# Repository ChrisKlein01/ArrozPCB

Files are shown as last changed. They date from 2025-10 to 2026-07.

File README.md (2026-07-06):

# IoT System for Water Management in Rice Paddies

Embedded IoT system for LoRa + GPS telemetry, integrating custom hardware, embedded firmware, iterative PCB design, and a Node-RED backend.

## Final Prototype (V3)

The following images show selected views of the final hardware prototype (V3).

### Enclosure

<p align="center">
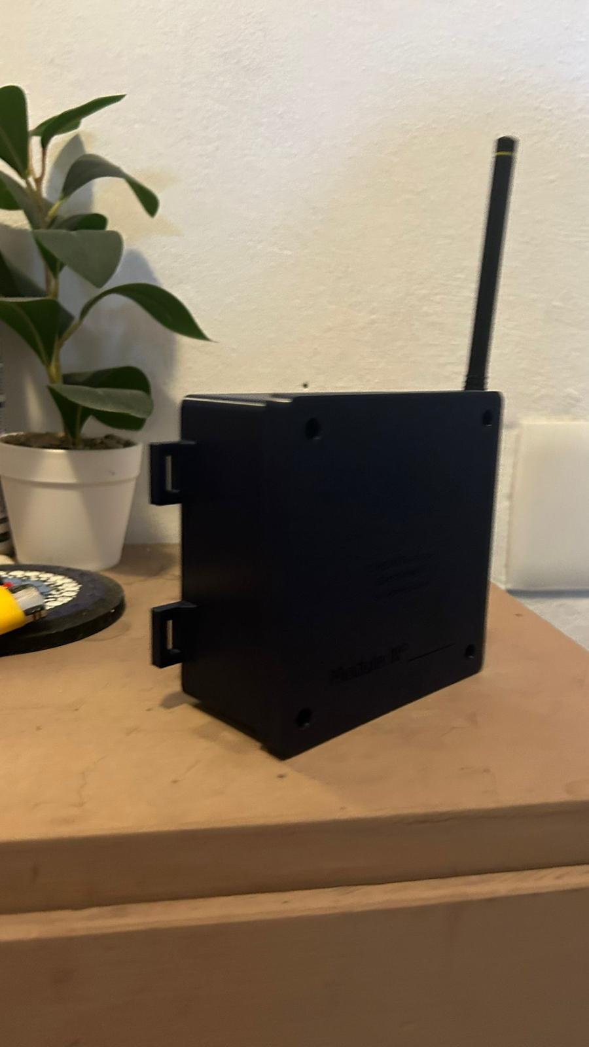
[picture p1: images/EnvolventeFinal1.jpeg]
  
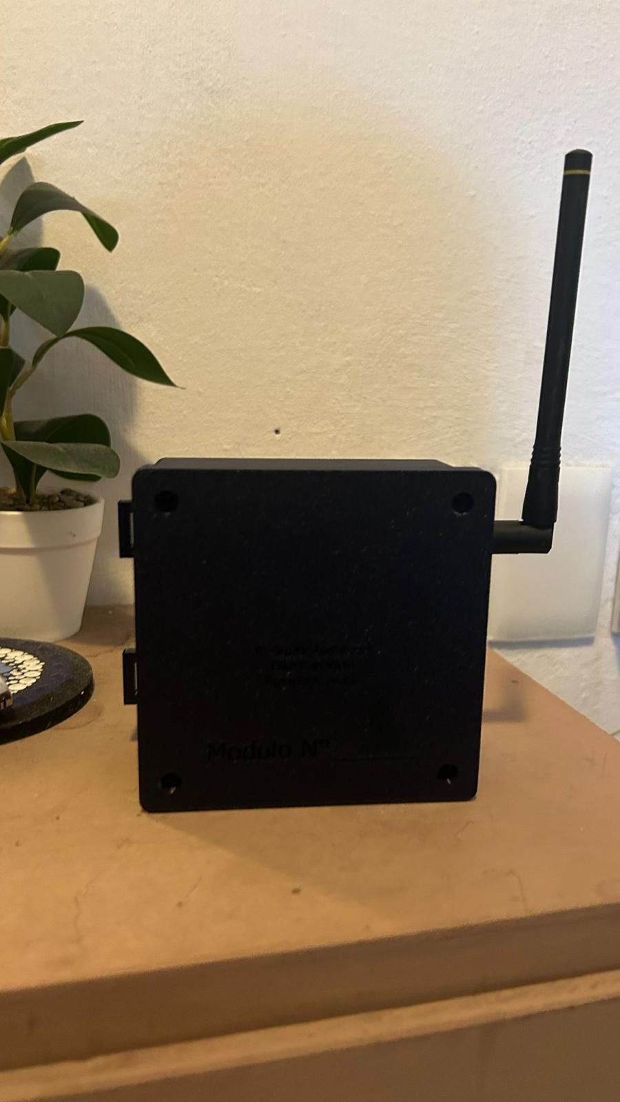
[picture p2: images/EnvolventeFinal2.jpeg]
  
</p>

### Custom PCB

<p align="center">
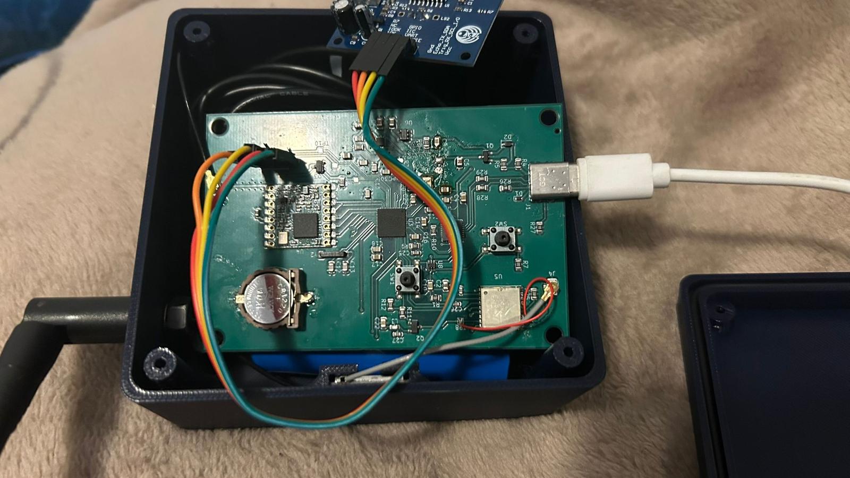
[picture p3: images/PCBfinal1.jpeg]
  
</p>

<p align="center">
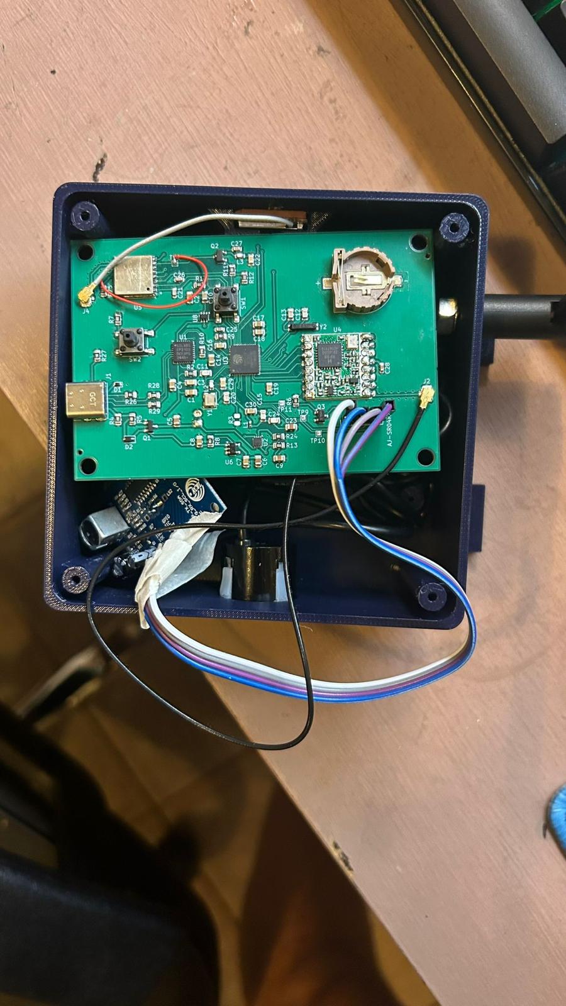
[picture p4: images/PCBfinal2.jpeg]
  
</p>

### Auxiliary Modules
For example, Power management and USB to UART modules.
<p align="center">
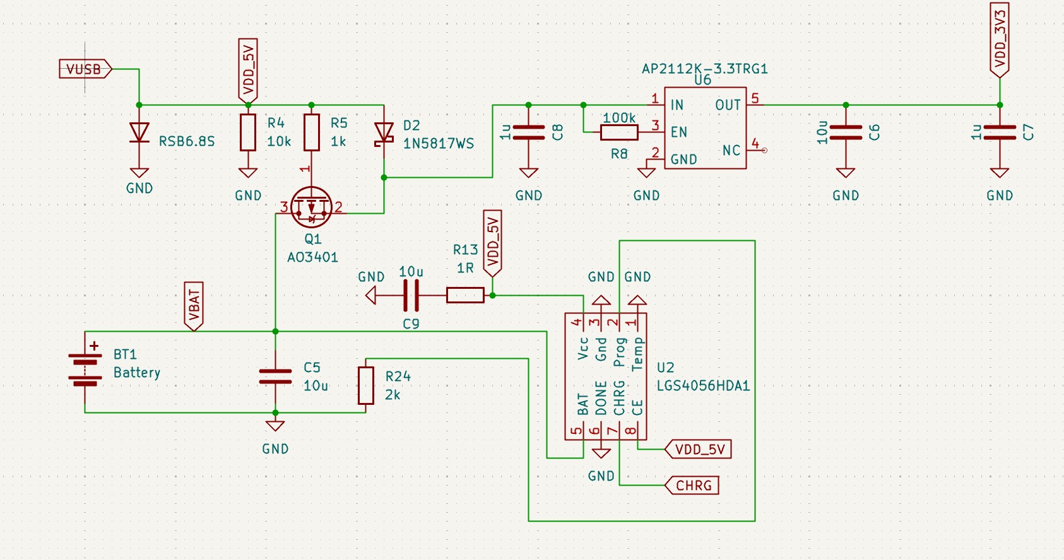
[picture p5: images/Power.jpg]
  
</p>

<p align="center">
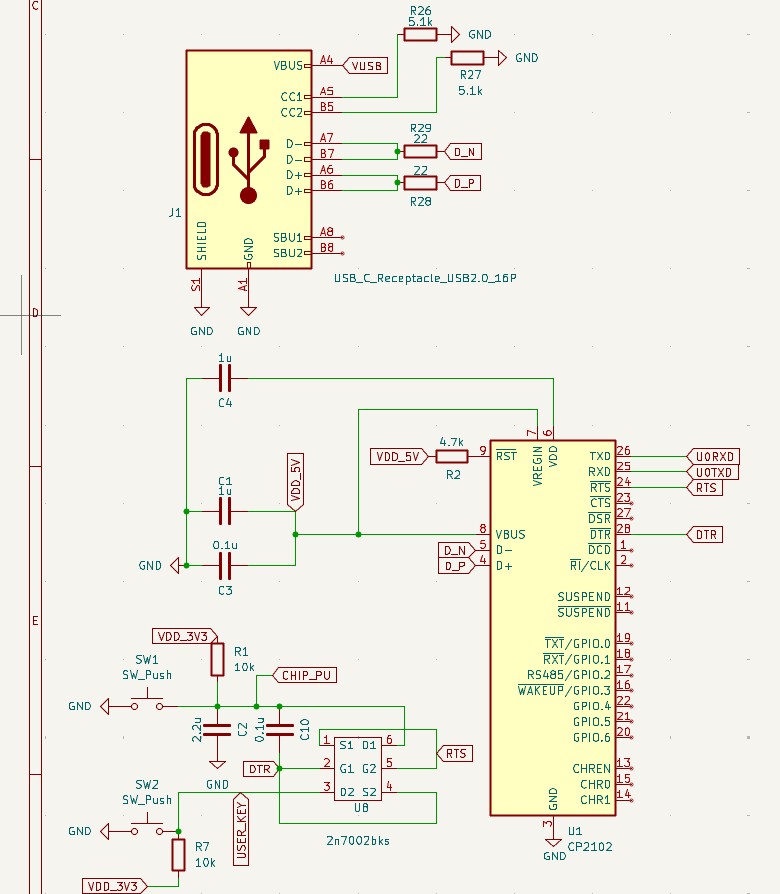
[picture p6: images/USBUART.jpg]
  
</p>

<h2>Firmware Flow Diagram</h2>

<p align="center">
  
</p>

## System Overview

End-to-end IoT prototype for wireless telemetry using LoRa communication and GPS data acquisition, covering proof-of-concept validation, custom hardware development, embedded firmware, iterative PCB design, and a complete Node-RED data processing pipeline.

---

## Repository Structure

- `Codigo_lilygo/`  
  Proof-of-concept implementation using a LilyGO T3 v1.6.1 development board. Used for early validation of LoRa communication and end-to-end data flow through an initial Node-RED pipeline before custom PCB and GPS integration.

- `Firmware/`  
  Main embedded firmware for the custom PCB. Handles GPS acquisition, LoRa communication, and system logic.

- `Node Red/`  
  Node-RED flows for telemetry ingestion, processing, and visualization.

- `Envolvente/`  
  Mechanical enclosure design for system housing and protection.

- `V1.0/`  
  First PCB iteration used to validate the custom LoRa hardware.

- `V2.0/`  
  PCB redesign incorporating GPS integration and correcting initial hardware issues.

- `V3.0/`  
  Final PCB revision with optimized layout and complete system integration.

- `.gitignore`  
  Git ignore rules for build artifacts and temporary files.

- `README.md`  
  Project documentation.

---

## Development Flow

1. Proof-of-concept on a LilyGO T3 development board.
2. Validation of LoRa communication and the initial telemetry pipeline using Node-RED.
3. Design and validation of the first custom PCB (V1.0).
4. PCB redesign with GPS integration and hardware improvements (V2.0).
5. Final optimized hardware revision with complete system integration (V3.0).
6. Integration with the Node-RED backend and end-to-end system validation.

---

## Project Scope

The project covers the complete development cycle of an embedded IoT system, including:

- Embedded firmware development (C/C++)
- Custom electronic circuit design
- Schematic capture and PCB design (KiCad)
- PCB assembly and soldering
- LoRa wireless communication
- GPS integration
- MQTT-based telemetry
- Node-RED backend development
- Mechanical enclosure design

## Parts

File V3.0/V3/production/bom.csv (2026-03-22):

Designator | Footprint | Quantity | Value | LCSC Part #
AJ-SR04M1 | PinHeader_1x04_P2.54mm_Vertical | 1 | U3 | C7243
BT1 | JST_EH_S2B-EH_1x02_P2.50mm_Horizontal | 1 | Battery
BT2 | pila | 1 | 1056TR | C238068
C1, C14, C17, C4, C7, C8 | 0805 | 6 | 1u
C10, C16, C18, C19, C3, C30 | 0805 | 6 | 0.1u
C11 | 0805 | 1 | 15p
C12, C13 | 0805 | 2 | 4.7p
C15 | 0805 | 1 | 2.2p
C2 | 0805 | 1 | 2.2u
C20 | 0805 | 1 | 18p
C21, C25, C26, C27 | 0603 | 4 | 56pF
C22 | 0805 | 1 | 10nF
C23, C5, C6, C9 | 0805 | 4 | 10u
C24 | 0805 | 1 | 1.8p
C28 | 0603 | 1 | 10u
C29 | 0805 | 1 | 10n
D1 | D_SOD-523 | 1 | RSB6.8S | C28646388
D2 | D_SOD-323 | 1 | 1N5817WS | C727114
J1 | USB_C_Receptacle_GCT_USB4085 | 1 | USB_C_Receptacle_USB2.0_16P | C7095263
J2, J4 | U.FL_Hirose_U.FL-R-SMT-1_Vertical | 2 | Conn_Coaxial_Small | C88373
L1 | 0402 | 1 | 2.0n | C18216
L2 | 0603 | 1 | 22n | C12099
L3 | 0603 | 1 | 27nH | C12100
Q1 | SOT-23 | 1 | AO3401 | C181091
Q2 | SOT-23 | 1 | AO3401A | C15127
Q3 | SOT-23 | 1 | AO3400A | C20917
R1, R12, R25, R4, R7 | 0805 | 5 | 10k
R10 | 0805 | 1 | 499
R11, R5 | 0805 | 2 | 1k
R13 | 0805 | 1 | 1R
R2 | 0805 | 1 | 4.7k
R24 | 0805 | 1 | 2k
R26, R27 | 0805 | 2 | 5.1k
R28, R29 | 0805 | 2 | 22
R3 | 0805 | 1 | 50 NC
R6, R8, R9 | 0805 | 3 | 100k
SW1, SW2 | SW_SPST_PTS645Sx43SMTR92 | 2 | SW_Push | C49234152
TP10, TP11, TP8, TP9 | TestPoint_Pad_1.0x1.0mm | 4 | TestPoint
U1 | QFN-28-1EP_5x5mm_P0.5mm_EP3.35x3.35mm | 1 | CP2102 | C6568
U2 | DFN-8-1EP_2x2mm_P0.5mm_EP0.6x1.2mm | 1 | LGS4056HDA1 | C5124109
U3 | QFN-56-1EP_7x7mm_P0.4mm_EP4x4mm | 1 | ESP32-S3FN8 | C2913196
U4 | HOPERF_RFM9XW_SMD | 1 | RFM95W-915S2
U5 | Teseo | 1 | TESEO-LIV3R
U6 | SOT-23-5 | 1 | AP2112K-3.3TRG1 | C23380830
U8 | SOT-363_SC-70-6 | 1 | 2n7002bks | C68181
Y1 | Crystal_SMD_3225-4Pin_3.2x2.5mm | 1 | Crystal 40MHz/10ppm | C5380316
Y2 | Crystal_SMD_SeikoEpson_MC146-4Pin_6.7x1.5mm | 1 | 32.768KHz/ESR≤70KΩ | C15482

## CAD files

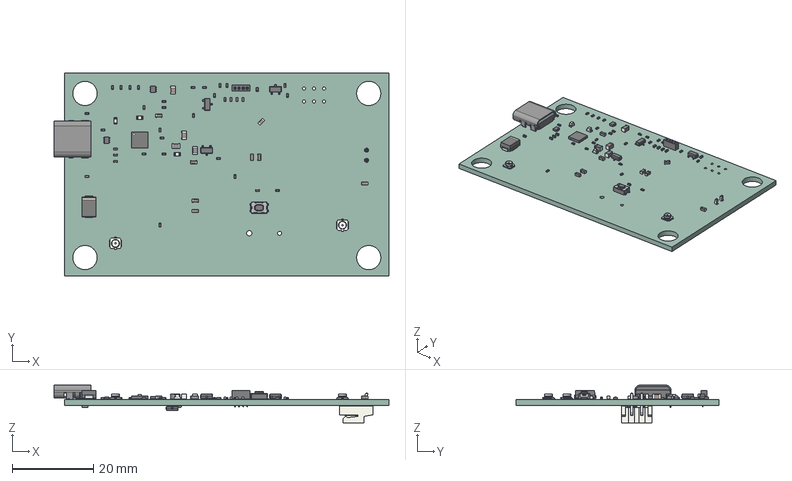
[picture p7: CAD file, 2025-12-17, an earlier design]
v2.0/PCB_LoRa+GPS.step
82.6 x 50.0 x 9.33 mm
C_0402_1005Metric x 10
C_0805_2012Metric x 2
R_0402_1005Metric x 27
LED_0603_1608Metric x 3
SOT-23 x 4
C_0603_1608Metric x 8
U.FL_Hirose_U.FL-R-SMT-1_Vertical x 2
SW_Push_1P1T_NO_CK_KMR2
D_SMB
QFN-24-1EP_4x4mm_P0.5mm_EP2.6x2.6mm
PinSocket_1x04_P1.00mm_Vertical
L_0805_2012Metric x 2
SOT-563
USB_C_Receptacle_GCT_USB4085
SOT-666
JST_EH_S2B-EH_1x02_P2.50mm_Horizontal
PCB_LoRa+GPS_PCB

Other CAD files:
Envolvente/CajaTesisV2.ipt

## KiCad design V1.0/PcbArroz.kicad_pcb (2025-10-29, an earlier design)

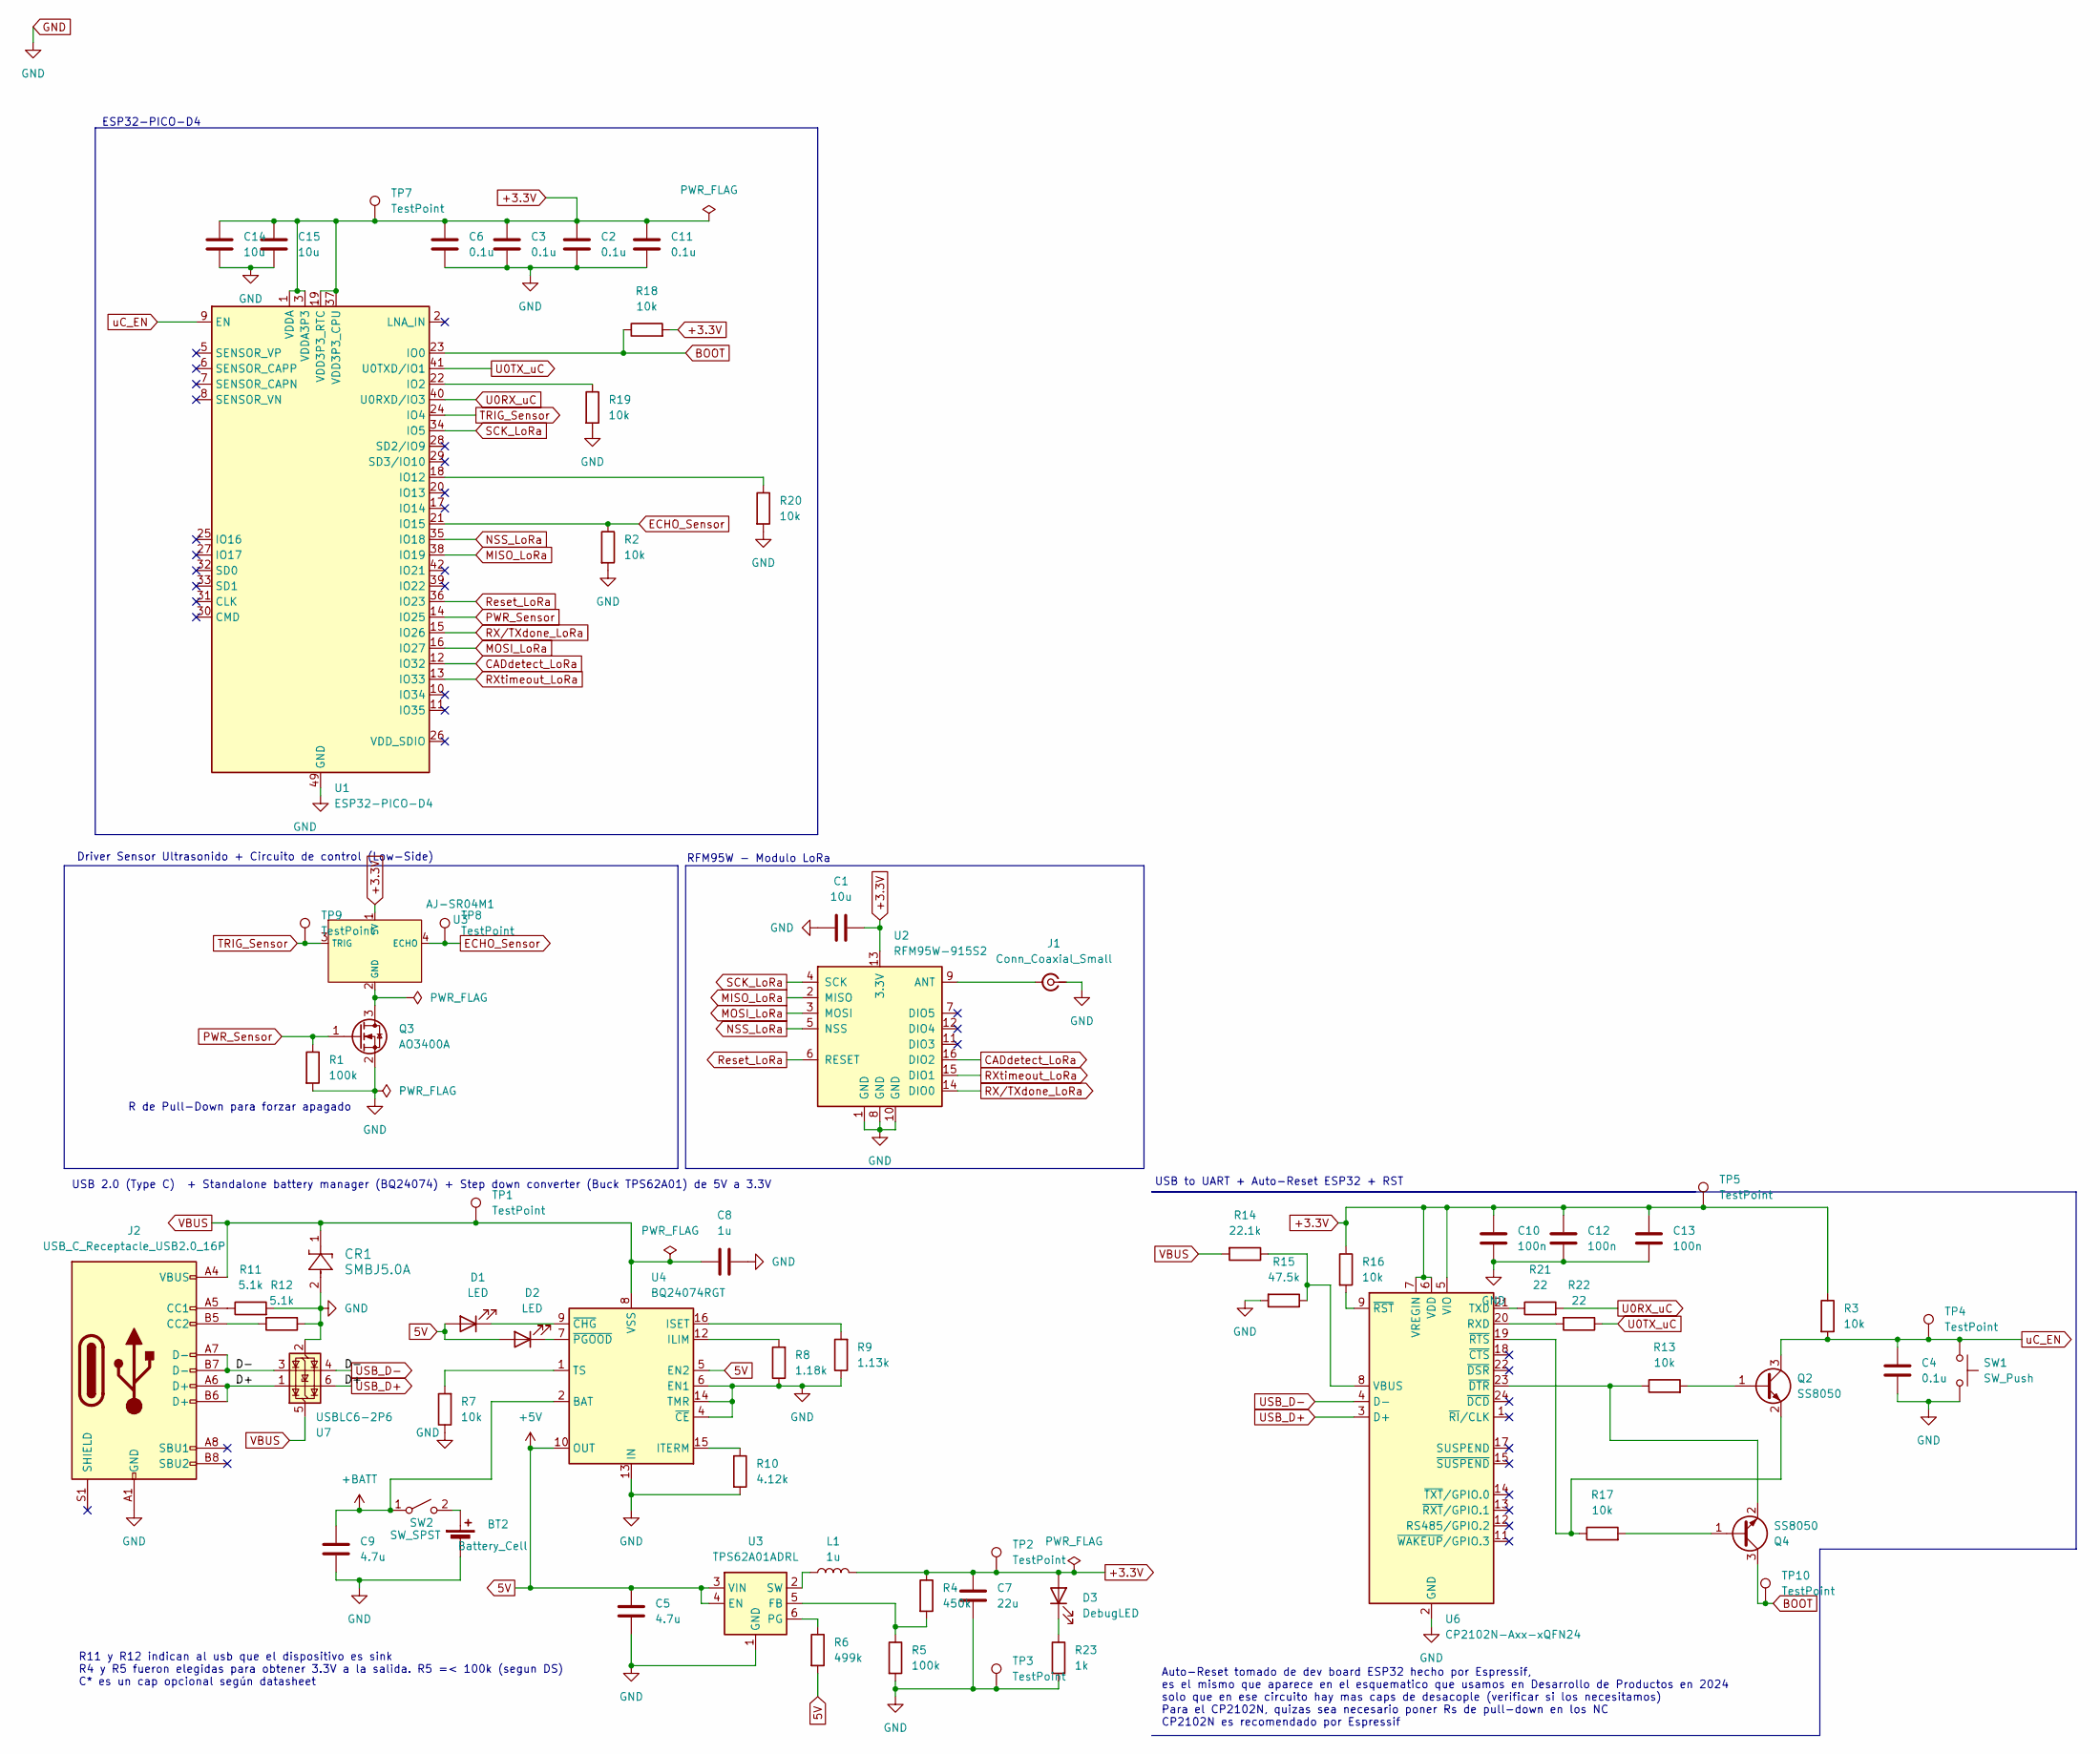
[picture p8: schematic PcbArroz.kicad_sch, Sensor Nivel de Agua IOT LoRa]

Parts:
AJ-SR04M1: U3; PinSocket_1x04_P2.54mm_Vertical
BT2: Battery_Cell; JST_EH_S2B-EH_1x02_P2.50mm_Horizontal
C1, C14, C15: 10u; C_0603_1608Metric
C2, C3, C4, C6, C11: 0.1u; C_0402_1005Metric
C5: 4.7u; C_0603_1608Metric
C7: 22u; C_0805_2012Metric
C8: 1u; C_0402_1005Metric
C9: 4.7u; C_0402_1005Metric
C10, C12, C13: 100n; C_0402_1005Metric
CR1: SMBJ5.0A; D_SMB
D1, D2: LED; LED_0603_1608Metric
D3: DebugLED; LED_0603_1608Metric
J1: Conn_Coaxial_Small; U.FL_Molex_MCRF_73412-0110_Vertical
J2: USB_C_Receptacle_USB2.0_16P; USB_C_Receptacle_GCT_USB4085
L1: 1u; C_0402_1005Metric
Q2, Q4: SS8050; SOT-23
Q3: AO3400A; SOT-23
R1, R5: 100k; R_0402_1005Metric
R2, R3, R7, R13, R16, R17, R18, R19, R20: 10k; R_0402_1005Metric
R4: 450k; R_0402_1005Metric
R6: 499k; R_0402_1005Metric
R8: 1.18k; R_0402_1005Metric
R9: 1.13k; R_0402_1005Metric
R10: 4.12k; R_0402_1005Metric
R11, R12: 5.1k; R_0402_1005Metric
R14: 22.1k; R_0402_1005Metric
R15: 47.5k; R_0402_1005Metric
R21, R22: 22; R_0402_1005Metric
R23: 1k; R_0402_1005Metric
SW1: SW_Push; SW_Push_1P1T_NO_Vertical_Wuerth_434133025816
SW2: SW_SPST; SW_DIP_SPSTx01_Slide_6.7x4.1mm_W7.62mm_P2.54mm_LowProfile
TP1, TP2, TP3, TP4, TP5, TP7, TP8, TP9, TP10: TestPoint; TestPoint_Pad_1.0x1.0mm
U1: ESP32-PICO-D4; QFN-48-1EP_7x7mm_P0.5mm_EP5.3x5.3mm
U2: RFM95W-915S2; HOPERF_RFM9XW_SMD
U3: TPS62A01ADRL; SOT-563
U4: BQ24074RGT; VQFN-16-1EP_3x3mm_P0.5mm_EP1.6x1.6mm
U6: CP2102N-Axx-xQFN24; QFN-24-1EP_4x4mm_P0.5mm_EP2.6x2.6mm
U7: USBLC6-2P6; SOT-666

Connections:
5V: C5.1, D1.2 (A), D2.2 (A), R6.2, U3.3 (VIN), U3.4 (EN), U4.5 (EN2), U4.10 (OUT), U4.11 (OUT)
+3.3V: AJ-SR04M1.1 (5V), C1.1, C2.1, C3.1, C6.1, C7.1, C10.1, C11.1, C12.1, C13.1, C14.1, C15.1, D3.2 (A), L1.2, R3.1, R4.1, R16.1, R18.2, TP2.1, TP5.1, TP7.1, U1.1 (VDDA), U1.3 (VDDA3P3), U1.4 (VDDA3P3), U1.19 (VDD3P3_RTC), U1.37 (VDD3P3_CPU), U1.43 (VDDA), U1.46 (VDDA), U2.13 (3.3V), U6.5 (VIO), U6.6 (VDD), U6.7 (VREGIN)
+BATT: C9.1, SW2.1 (A), U4.2 (BAT), U4.3 (BAT)
BOOT: Q4.3 (C), R18.1, TP10.1, U1.23 (IO0)
CADdetect_LoRa: U1.12 (IO32), U2.16 (DIO2)
ECHO_Sensor: AJ-SR04M1.4 (ECHO), R2.1, TP8.1, U1.21 (IO15)
GND: BT2.2 (-), C1.2, C2.2, C3.2, C4.2, C5.2, C6.2, C7.2, C8.1, C9.2, C10.2, C11.2, C12.2, C13.2, C14.2, C15.2, CR1.2, J1.1 (In), J2.A1 (GND), J2.A12 (GND), J2.B1 (GND), J2.B12 (GND), Q3.2 (S), R1.2, R2.2, R5.2, R7.1, R8.1, R9.1, R10.2, R11.2, R12.1, R15.2, R19.2, R20.2, R23.2, SW1.2, TP3.1, U1.49 (GND), U2.1 (GND), U2.8 (GND), U2.10 (GND), U3.1 (GND), U4.4 (~CE), U4.6 (EN1), U4.13 (IN), U4.14 (TMR), U6.2 (GND), U6.25 (GND), U7.2 (GND)
MISO_LoRa: U1.38 (IO19), U2.2 (MISO)
MOSI_LoRa: U1.16 (IO27), U2.3 (MOSI)
NSS_LoRa: U1.35 (IO18), U2.5 (NSS)
unnamed: AJ-SR04M1.2 (GND), Q3.3 (D)
unnamed: BT2.1 (+), SW2.2 (B)
unnamed: D1.1 (K), U4.9 (~CHG)
unnamed: D2.1 (K), U4.7 (~PGOOD)
unnamed: D3.1 (K), R23.1
unnamed: J1.2 (Ext), U2.9 (ANT)
unnamed: J2.A5 (CC1), R11.1
unnamed: J2.B5 (CC2), R12.2
unnamed: Q2.1 (B), R13.2
unnamed: Q2.2 (E), R17.1, U6.19 (~RTS)
unnamed: Q4.1 (B), R17.2
unnamed: Q4.2 (E), R13.1, U6.23 (~DTR)
unnamed: R19.1, U1.22 (IO2)
unnamed: R20.1, U1.18 (IO12)
unnamed: R4.2, R5.1, U3.5 (FB)
unnamed: R6.1, U3.6 (PG)
unnamed: L1.1, U3.2 (SW)
unnamed: R8.2, U4.12 (ILIM)
unnamed: R9.2, U4.16 (ISET)
unnamed: R10.1, U4.15 (ITERM)
unnamed: R7.2, U4.1 (TS)
unnamed: R22.2, U6.20 (RXD)
unnamed: R21.1, U6.21 (TXD)
unnamed: R14.1, R15.1, U6.8 (VBUS)
unnamed: R16.2, U6.9 (~RST)
PWR_Sensor: Q3.1 (G), R1.1, U1.14 (IO25)
RXtimeout_LoRa: U1.13 (IO33), U2.15 (DIO1)
RX/TXdone_LoRa: U1.15 (IO26), U2.14 (DIO0)
Reset_LoRa: U1.36 (IO23), U2.6 (RESET)
SCK_LoRa: U1.34 (IO5), U2.4 (SCK)
TRIG_Sensor: AJ-SR04M1.3 (TRIG), TP9.1, U1.24 (IO4)
U0RX_uC: R21.2, U1.40 (U0RXD/IO3)
U0TX_uC: R22.1, U1.41 (U0TXD/IO1)
USB_D+: J2.A6 (D+), J2.B6 (D+), U6.3 (D+), U7.1 (I/O1), U7.6 (I/O1)
USB_D-: J2.A7 (D-), J2.B7 (D-), U6.4 (D-), U7.3 (I/O2), U7.4 (I/O2)
VBUS: C8.2, CR1.1, J2.A4 (VBUS), J2.A9 (VBUS), J2.B4 (VBUS), J2.B9 (VBUS), R14.2, TP1.1, U4.8 (VSS), U4.17 (VSS), U7.5 (VBUS)
uC_EN: C4.1, Q2.3 (C), R3.2, SW1.1, TP4.1, U1.9 (EN)

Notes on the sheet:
Auto-Reset tomado de dev board ESP32 hecho por Espressif, es el mismo que aparece en el esquematico que usamos en Desarrollo de Productos en 2024 solo que en ese circuito hay mas caps de desacople (verificar si los necesitamos) Para el CP2102N, quizas sea necesario poner Rs de pull-down en los NC C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
USB to UART + Auto-Reset ESP32 + RST
Driver Sensor Ultrasonido + Circuito de control (Low-Side)
USB 2.0 (Type C) + Standalone battery manager (BQ24074) + Step down converter (Buck TPS62A01) de 5V a 3.3V
ESP32-PICO-D4
R de Pull-Down para forzar apagado
R11 y R12 indican al usb que el dispositivo es sink R4 y R5 fueron elegidas para obtener 3.3V a la salida. R5 =< 100k (segun DS) C* es un cap opcional según datasheet
RFM95W - Modulo LoRa

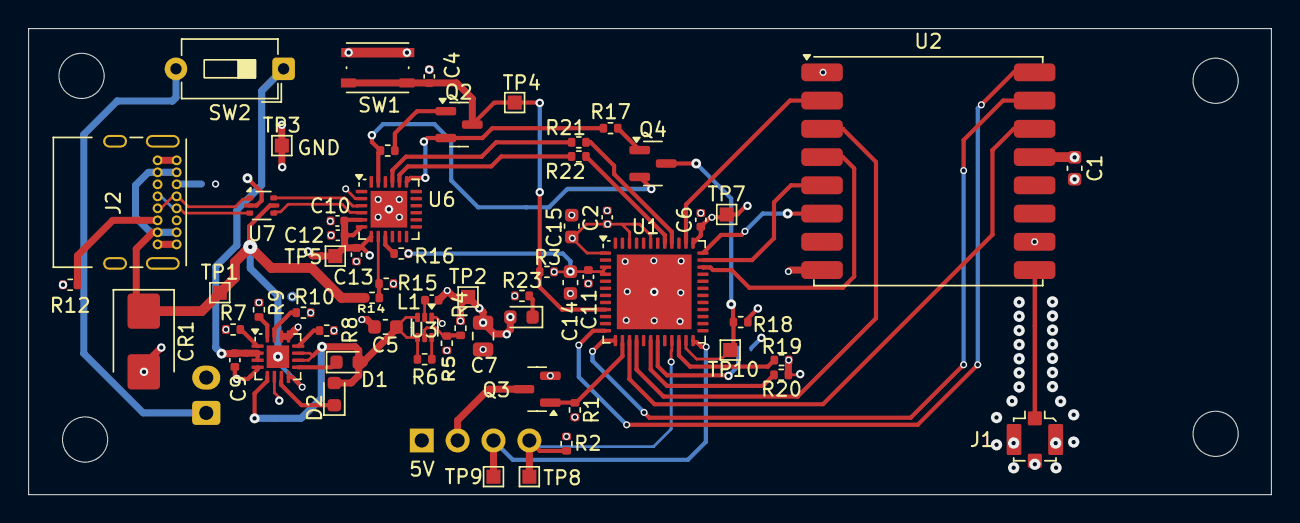
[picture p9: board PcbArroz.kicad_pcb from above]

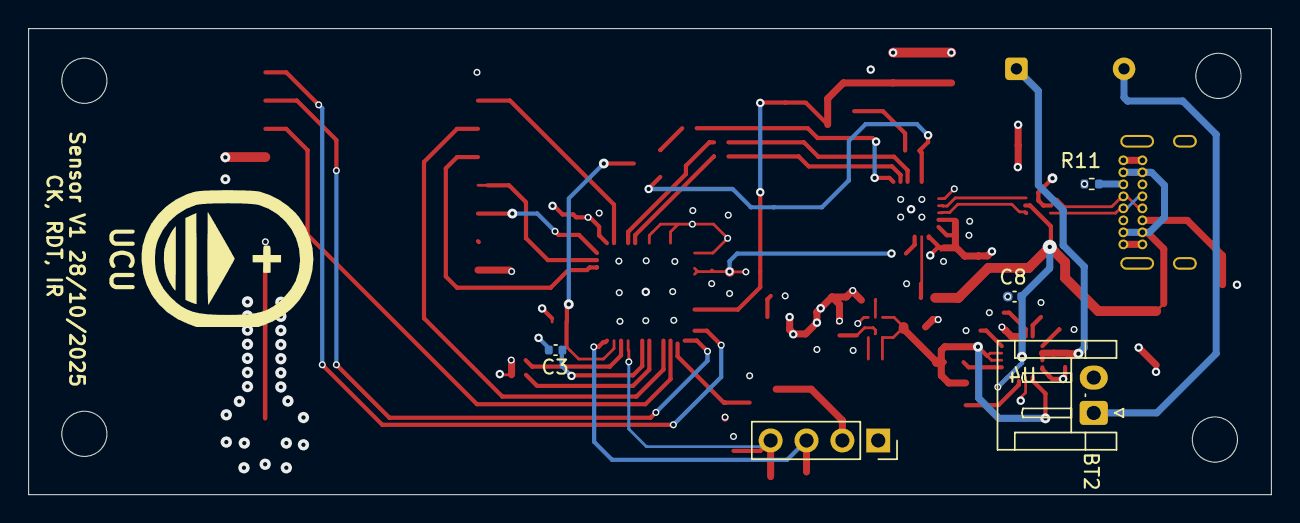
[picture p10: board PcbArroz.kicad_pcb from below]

Board: 4 copper layers, 88.0 x 33.0 mm, 68 parts (6 on the bottom side), 47 nets.

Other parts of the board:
UCU: LOGO; LogoUCU

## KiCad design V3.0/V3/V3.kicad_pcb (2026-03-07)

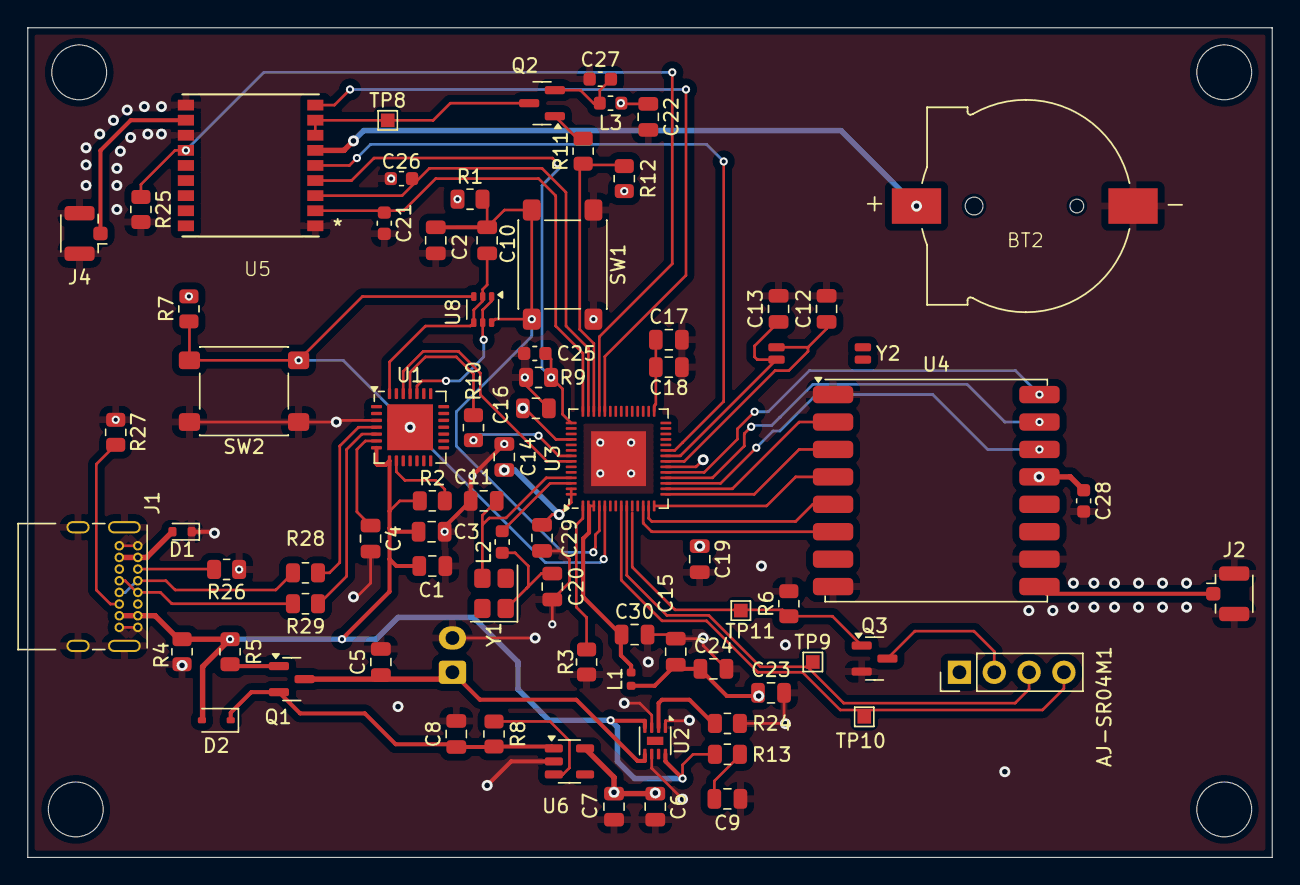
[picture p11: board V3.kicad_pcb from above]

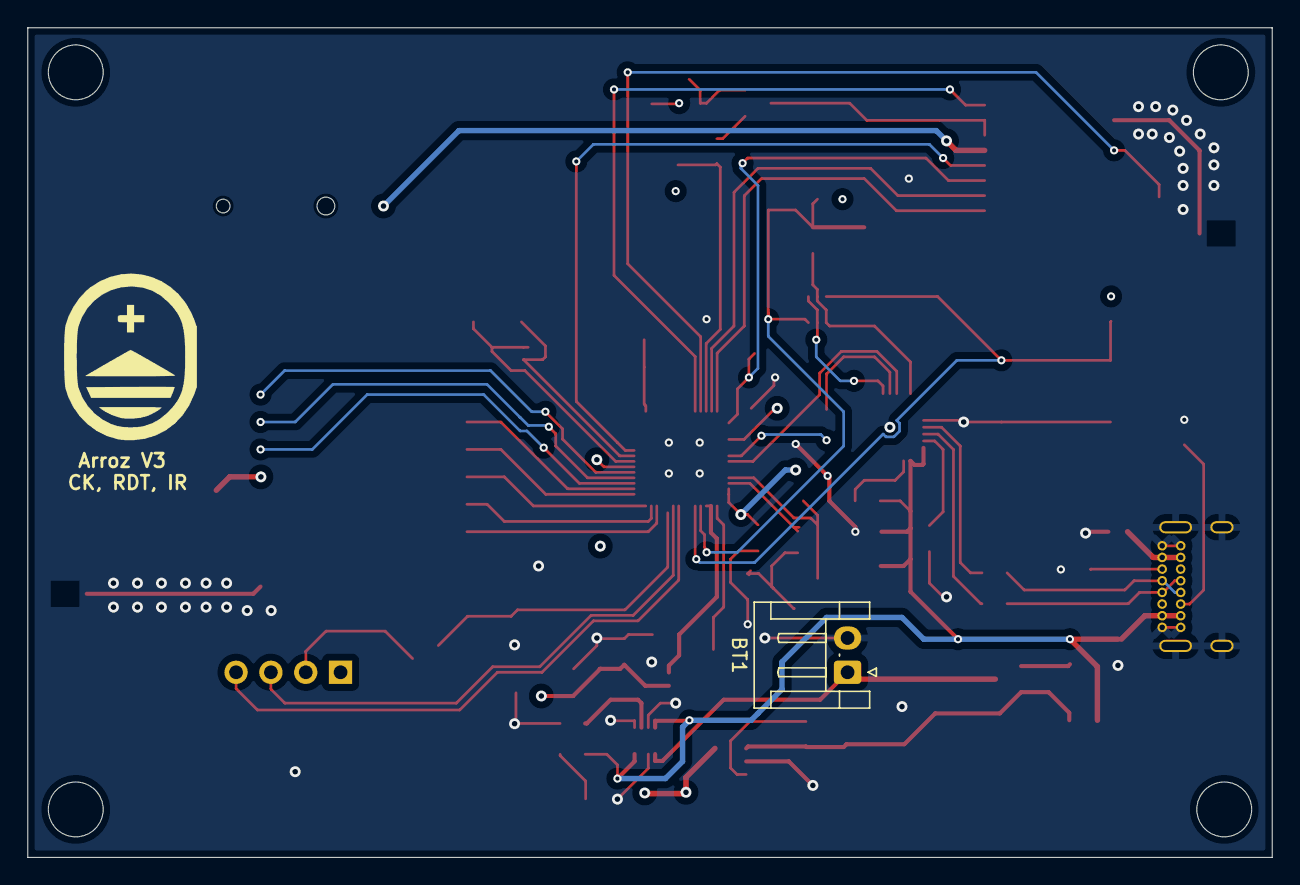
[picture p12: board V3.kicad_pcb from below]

Board: 4 copper layers, 90.8 x 60.5 mm, 79 parts (2 on the bottom side), 57 nets.

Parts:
AJ-SR04M1: U3; PinHeader_1x04_P2.54mm_Vertical
BT1: Battery; JST_EH_S2B-EH_1x02_P2.50mm_Horizontal
BT2: 1056TR; pila
C1, C4, C7, C8, C14, C17: 1u; C_0805_2012Metric
C2: 2.2u; C_0805_2012Metric
C3, C10, C16, C18, C19, C30: 0.1u; C_0805_2012Metric
C5, C6, C9, C23: 10u; C_0805_2012Metric
C11: 15p; C_0805_2012Metric
C12, C13: 4.7p; C_0805_2012Metric
C15: 2.2p; C_0805_2012Metric
C20: 18p; C_0805_2012Metric
C21, C25, C26, C27: 56pF; C_0603_1608Metric
C22: 10nF; C_0805_2012Metric
C24: 1.8p; C_0805_2012Metric
C28: 10u; C_0603_1608Metric
C29: 10n; C_0805_2012Metric
D1: RSB6.8S; D_SOD-523
D2: 1N5817WS; D_SOD-323
J1: USB_C_Receptacle_USB2.0_16P; USB_C_Receptacle_GCT_USB4085
J2, J4: Conn_Coaxial_Small; U.FL_Hirose_U.FL-R-SMT-1_Vertical
L1: 2.0n; L_0402_1005Metric
L2: 22n; L_0603_1608Metric
L3: 27nH; L_0603_1608Metric
Q1: AO3401; SOT-23
Q2: AO3401A; SOT-23
Q3: AO3400A; SOT-23
R1, R4, R7, R12, R25: 10k; R_0805_2012Metric
R2: 4.7k; R_0805_2012Metric
R3: 50 NC; R_0805_2012Metric
R5, R11: 1k; R_0805_2012Metric
R6, R8, R9: 100k; R_0805_2012Metric
R10: 499; R_0805_2012Metric
R13: 1R; R_0805_2012Metric
R24: 2k; R_0805_2012Metric
R26, R27: 5.1k; R_0805_2012Metric
R28, R29: 22; R_0805_2012Metric
SW1, SW2: SW_Push; SW_SPST_PTS645Sx43SMTR92
TP8, TP9, TP10, TP11: TestPoint; TestPoint_Pad_1.0x1.0mm
U1: CP2102; QFN-28-1EP_5x5mm_P0.5mm_EP3.35x3.35mm
U2: LGS4056HDA1; DFN-8-1EP_2x2mm_P0.5mm_EP0.6x1.2mm
U3: ESP32-S3FN8; QFN-56-1EP_7x7mm_P0.4mm_EP4x4mm
U4: RFM95W-915S2; HOPERF_RFM9XW_SMD
U5: TESEO-LIV3R; Teseo
U6: AP2112K-3.3TRG1; SOT-23-5
U8: 2n7002bks; SOT-363_SC-70-6
UCU: LOGO; LogoUCU
Y1: Crystal 40MHz/10ppm; Crystal_SMD_3225-4Pin_3.2x2.5mm
Y2: 32.768KHz/ESR≤70KΩ; Crystal_SMD_SeikoEpson_MC146-4Pin_6.7x1.5mm

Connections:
32K_XN: C13.1, U3.22 (XTAL_32K_N), Y2.1
32K_XP: C12.1, U3.21 (XTAL_32K_P), Y2.4
AntOff_GPS: R25.1, U3.39 (GPIO34), U5.13 (ANT_OFF)
CADdetect_LoRa: U3.19 (GPIO14), U4.16 (DIO2)
CHIP_PU: C2.1, C10.1, R1.2, SW1.2, U3.4 (CHIP_PU), U8.6 (D1)
DTR: C10.2, U1.28 (~DTR), U8.2 (G1), U8.4 (S2)
D_N: R29.1, U1.5 (D-)
D_P: R28.1, U1.4 (D+)
ECHO_Sensor: AJ-SR04M1.4 (ECHO), TP10.1, U3.8 (GPIO3)
GND: BT1.2 (-), BT2.N, C1.2, C2.2, C3.2, C4.2, C5.2, C6.2, C7.2, C8.2, C9.2, C11.2, C12.2, C13.2, C14.2, C15.2, C16.2, C17.2, C18.2, C19.2, C20.2, C21.2, C22.2, C23.2, C24.2, C25.2, C26.2, C27.1, C28.2, C29.2, C30.2, D1.1 (K), J1.A1 (GND), J1.A12 (GND), J1.B1 (GND), J1.B12 (GND), J1.S1 (SHIELD), J2.2 (Ext), J4.2 (Ext), Q3.2 (S), R3.2, R4.2, R6.2, R9.2, R24.1, R25.2, R26.1, R27.1, SW1.1, SW2.1, U1.3 (GND), U1.29 (GND), U2.1 (Temp), U2.3 (Gnd), U2.6 (DONE), U3.57 (GND), U4.1 (GND), U4.8 (GND), U4.10 (GND), U5.1 (GND), U5.10 (GND_RF), U5.12 (GND_RF), U6.2 (GND)
MISO_LoRa: U3.15 (GPIO10), U4.3 (MOSI)
MOSI_LoRa: U3.16 (GPIO11), U4.2 (MISO)
NSS_LoRa: U3.13 (GPIO8), U4.5 (NSS)
unnamed: AJ-SR04M1.2 (GND), Q3.3 (D)
unnamed: C9.1, R13.1
unnamed: C30.1, L1.2, U3.2 (VDD3P3), U3.3 (VDD3P3)
unnamed: C8.1, D2.1 (K), Q1.2 (S), R8.1, U6.1 (IN)
unnamed: J1.A5 (CC1), R26.2
unnamed: J1.B5 (CC2), R27.2
unnamed: J1.A6 (D+), J1.B6 (D+), R28.2
unnamed: J1.A7 (D-), J1.B7 (D-), R29.2
unnamed: J2.1 (In), U4.9 (ANT)
unnamed: J4.1 (In), U5.11 (RF_IN)
unnamed: Q1.1 (G), R5.2
unnamed: Q2.3 (D), TP8.1, U5.7 (VCC_IO), U5.8 (VCC)
unnamed: C27.2, L3.2, Q2.2 (S)
unnamed: C4.1, U1.6 (VDD)
unnamed: R2.2, U1.9 (~RST)
unnamed: R24.2, U2.2 (Prog)
unnamed: R11.1, R12.1, U3.40 (GPIO35)
unnamed: R3.1, U3.1 (LNA_IN)
unnamed: R10.2, U3.49 (U0TXD)
unnamed: C17.1, C18.1, U3.29 (VDD_SPI)
unnamed: L2.2, U3.54 (XTAL_P)
unnamed: R8.2, U6.3 (EN)
PPS_GPS: C25.1, R9.1, U3.43 (GPIO38), U5.4 (1PPS)
PWR_Sensor: Q3.1 (G), R6.1, TP11.1, U3.10 (GPIO5)
Pnp_Gps: Q2.1 (G), R11.2
RTS: U1.24 (~RTS), U8.1 (S1), U8.5 (G2)
RXtimeout_LoRa: U3.18 (GPIO13), U4.15 (DIO1)
RX/TXdone_LoRa: U3.17 (GPIO12), U4.14 (DIO0)
Reset_GPS: U3.38 (GPIO33), U5.9 (SYS_RSTn)
Reset_LoRa: U3.12 (GPIO7), U4.6 (RESET)
Rx_GPS: C26.1, U3.41 (GPIO36), U5.3 (RX)
SCK_LoRa: U3.14 (GPIO9), U4.4 (SCK)
TRIG_Sensor: AJ-SR04M1.3 (TRIG), TP9.1, U3.9 (GPIO4)
Tx_GPS: C21.1, U3.42 (GPIO37), U5.2 (TX)
U0RXD: U1.26 (TXD), U3.50 (U0RXD)
U0TXD: R10.1, U1.25 (RXD)
USER_KEY: R7.1, SW2.2, U3.5 (GPIO0), U8.3 (D2)
VBAT: BT1.1 (+), C5.1, Q1.3 (D), U2.5 (BAT)
VBatt: BT2.P, U5.6 (VBATT)
VDD_3V3: AJ-SR04M1.1 (5V), C6.1, C7.1, C14.1, C15.1, C16.1, C19.1, C22.1, C23.1, C24.1, C28.1, C29.1, L1.1, L3.1, R1.1, R7.2, R12.2, U3.20 (VDD3P3_RTC), U3.46 (VDD3P3_CPU), U3.55 (VDDA), U3.56 (VDDA), U4.13 (3.3V), U6.5 (OUT)
VDD_5V: C1.1, C3.1, D1.2 (A), D2.2 (A), J1.A4 (VBUS), J1.A9 (VBUS), J1.B4 (VBUS), J1.B9 (VBUS), R2.1, R4.1, R5.1, R13.2, U1.7 (VREGIN), U1.8 (VBUS), U2.4 (Vcc), U2.8 (CE)
Wake_GPS: U3.23 (GPIO17), U5.5 (Wake-Up)
XTAL_N: C11.1, U3.53 (XTAL_N), Y1.3
XTAL_P: C20.1, L2.1, Y1.1

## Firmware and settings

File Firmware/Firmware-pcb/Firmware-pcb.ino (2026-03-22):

/*
 * ============================================================================
 * MONITOREO NIVEL DE AGUA - ESP32-S3 + LoRaWAN + GPS
 * ============================================================================
 *
 * Hardware:
 *   - ESP32-S3
 *   - LoRa SX1276 / RFM95
 *   - Sensor ultrasónico RCWL-1655
 *   - GPS Teseo LIV3R
 *
 * Red: LoRaWAN OTAA via TTN / ChirpStack (US915)
 *
 * ----------------------------------------------------------------------------
 * FLUJOS DE EJECUCIÓN
 * ----------------------------------------------------------------------------
 *
 *   Primer boot:
 *     LoRa join → Medir → Enviar → GPS (90s) → Sleep
 *     (GPS queda en RTC para los ciclos siguientes)
 *
 *   Wake desde sleep (normal):
 *     Restaurar sesión → Medir → Enviar → Sleep
 *
 *   Wake desde sleep con downlink 0x03 pendiente:
 *     GPS (90s) → Restaurar sesión → Medir → Enviar → Sleep
 *     (coordenadas frescas en el payload de este ciclo)
 *
 * ----------------------------------------------------------------------------
 * PAYLOAD UPLINK (FPort 2) — 12 bytes
 * ----------------------------------------------------------------------------
 *   Byte  0     : flags de estado
 *                   bit 0 = GPS válido
 *                   bit 1 = medición de agua válida
 *                   bit 2 = GPS actualizado este ciclo
 *                   bit 3 = primer boot
 *   Byte  1-2   : nivel de agua en cm (uint16 big-endian, 0xFFFF = error)
 *   Byte  3-6   : latitud  × 10^6  (int32 big-endian)
 *   Byte  7-10  : longitud × 10^6  (int32 big-endian)
 *   Byte  11    : HDOP × 10 (uint8, 255 = inválido)
 *
 * ----------------------------------------------------------------------------
 * COMANDOS DOWNLINK (FPort 1)
 * ----------------------------------------------------------------------------
 *   0x01 [LSB] [MSB]  → cambiar intervalo en segundos (uint16 LE)
 *   0x02              → reiniciar placa
 *   0x03              → solicitar GPS en el próximo ciclo (timeout completo)
 *
 * ============================================================================
 */

#include <SPI.h>
#include <HardwareSerial.h>
#include <MicroNMEA.h>
#include <driver/rtc_io.h>
#include <esp_sleep.h>
#include <lmic.h>
#include <hal/hal.h>

// ============================================================================
// PINES
// ============================================================================

#define LORA_SCK      9
#define LORA_MISO    11
#define LORA_MOSI    10
#define LORA_NSS      8
#define LORA_RST      6
#define LORA_DIO0    12
#define LORA_DIO1    13
#define LORA_DIO2    14

#define TRIG_PIN         4
#define ECHO_PIN         3
#define SENSOR_PWR_PIN   5

#define GPS_RX      37
#define GPS_TX      36
#define PNP_GPS     35
#define RESET_GPS   33
#define PPS_PIN     38
#define ANT_OFF     34   // Output del Teseo — solo INPUT, no usar como salida
#define WAKE_GPS    17   // No utilizado

// ============================================================================
// CONFIGURACIÓN
// ============================================================================

#define ALTURA_SENSOR_CM   100
#define GPS_TIMEOUT_MS   450000
#define SENSOR_MUESTRAS       4
#define SENSOR_MIN_VALIDAS    2
#define DEFAULT_INTERVAL     2400

// ============================================================================
// CREDENCIALES OTAA
// ============================================================================

static const u1_t PROGMEM APPEUI[8] = {
    0x00, 0x00, 0x00, 0x00, 0x00, 0x00, 0x00, 0x00
};
static const u1_t PROGMEM DEVEUI[8] = {    //LSB
0xA1, 0x04, 0xCF, 0x4A, 0x79, 0x58, 0x29, 0x18
};
static const u1_t PROGMEM APPKEY[16] = {  //MSB
0xE2, 0x89, 0xD4, 0x61, 0xE7, 0xF2, 0x74, 0x56, 0xA4, 0x58, 0xE2, 0x98, 0x3B, 0x1D, 0xD7, 0x4C
};

void os_getArtEui(u1_t* buf) { memcpy_P(buf, APPEUI,  8); }
void os_getDevEui(u1_t* buf) { memcpy_P(buf, DEVEUI,  8); }
void os_getDevKey(u1_t* buf) { memcpy_P(buf, APPKEY, 16); }

const lmic_pinmap lmic_pins = {
    .nss            = LORA_NSS,
    .rxtx           = LMIC_UNUSED_PIN,
    .rst            = LORA_RST,
    .dio            = { LORA_DIO0, LORA_DIO1, LORA_DIO2 },
    .rxtx_rx_active = 0,
    .rssi_cal       = 10,
    .spi_freq       = 8000000
};

// ============================================================================
// RTC MEMORY
// ============================================================================

RTC_DATA_ATTR uint32_t  bootCount     = 0;
RTC_DATA_ATTR uint32_t  messageCount  = 0;
RTC_DATA_ATTR uint16_t  sleepInterval = DEFAULT_INTERVAL;

RTC_DATA_ATTR lmic_t    RTC_LMIC;
RTC_DATA_ATTR bool      session_valid = false;

RTC_DATA_ATTR bool      gpsConfigDone  = false;
RTC_DATA_ATTR bool      gpsRequested   = false;  // Downlink 0x03 pendiente
RTC_DATA_ATTR bool      lastGpsValid   = false;
RTC_DATA_ATTR int32_t   lastLat        = 0;
RTC_DATA_ATTR int32_t   lastLon        = 0;
RTC_DATA_ATTR int16_t   lastAlt        = 0;
RTC_DATA_ATTR uint8_t   lastHdop       = 255;

// ============================================================================
// VARIABLES GLOBALES
// ============================================================================

static osjob_t sendjob;
bool firstBoot    = false;
bool gpsEsteciclo = false;  // GPS fue actualizado en este ciclo

HardwareSerial gpsSerial(2);
char nmeaBuffer[100];
MicroNMEA nmea(nmeaBuffer, sizeof(nmeaBuffer));


// ============================================================================
// GPS
// ============================================================================

void gpsApagar() {
    gpsSerial.end();
    digitalWrite(PNP_GPS, HIGH);
    Serial.println("[GPS] Modulo apagado.");
}

void gpsEncender() {
    pinMode(PNP_GPS,   OUTPUT);
    pinMode(RESET_GPS, OUTPUT);

    digitalWrite(PNP_GPS, HIGH);
    delay(50);
    digitalWrite(PNP_GPS, LOW);

    digitalWrite(RESET_GPS, LOW);
    delay(50);
    digitalWrite(RESET_GPS, HIGH);

    Serial.println("[GPS] Encendiendo modulo...");
    delay(2000);  // Boot mínimo del Teseo

    gpsSerial.begin(9600, SERIAL_8N1, GPS_RX, GPS_TX);
    delay(200);
    while (gpsSerial.available()) gpsSerial.read();

    if (!gpsConfigDone) {
        Serial.println("[GPS] Configurando NMEA (primera vez)...");
        MicroNMEA::sendSentence(gpsSerial, "$PSTMSETPAR,1201,0x00000042");
        delay(200);
        MicroNMEA::sendSentence(gpsSerial, "$PSTMSAVEPAR");
        delay(300);
        gpsConfigDone = true;
        Serial.println("[GPS] Configuracion guardada.");
    }
}

/*
 * Busca fix GPS durante GPS_TIMEOUT_MS.
 * Actualiza RTC memory si obtiene fix.
 * Retorna true si obtuvo fix.
 */
bool gpsBuscarFix() {
    unsigned long inicio      = millis();
    unsigned long ultimoPrint = 0;

    Serial.printf("[GPS] Buscando fix (max %d s)...\n", GPS_TIMEOUT_MS / 1000);

    // Esperar fix válido
    while (millis() - inicio < GPS_TIMEOUT_MS) {
        while (gpsSerial.available()) nmea.process(gpsSerial.read());

        if (nmea.isValid()) break;

        if (millis() - ultimoPrint >= 10000) {
            ultimoPrint = millis();
            Serial.printf("[GPS] Esperando... sats: %d\n", nmea.getNumSatellites());
        }
        delay(10);
    }

    if (!nmea.isValid()) {
        Serial.println("[GPS] Timeout sin fix.");
        return false;
    }

    Serial.println("[GPS] Fix obtenido. Estabilizando (descartando 4 lecturas)...");

    // --- Warm-up: descartar las primeras 4 lecturas ---
    for (int i = 0; i < 4; i++) {
        unsigned long t = millis();
        while (millis() - t < 1000) {
            while (gpsSerial.available()) nmea.process(gpsSerial.read());
            delay(10);
        }
        Serial.printf("[GPS] Descartando lectura %d/4\n", i + 1);
    }

    // --- Tomar 7 lecturas ---
    float lats[7], lons[7];
    float alts[7];
    int   hdops[7];

    Serial.println("[GPS] Tomando 7 lecturas...");
    for (int i = 0; i < 7; i++) {
        unsigned long t = millis();
        while (millis() - t < 1000) {
            while (gpsSerial.available()) nmea.process(gpsSerial.read());
            delay(10);
        }
        lats[i]  = nmea.getLatitude()  / 1e6f;
        lons[i]  = nmea.getLongitude() / 1e6f;
        long alt = 0;
        alts[i]  = nmea.getAltitude(alt) ? (float)(alt / 1000) : 0.0f;
        hdops[i] = nmea.getHDOP();
        Serial.printf("[GPS] Lectura %d/7 — Lat: %.6f  Lon: %.6f\n", i + 1, lats[i], lons[i]);
    }

    // --- Descartar max y min de lat, promediar las 5 restantes ---
    int minIdx = 0, maxIdx = 0;
    for (int i = 1; i < 7; i++) {
        if (lats[i] < lats[minIdx]) minIdx = i;
        if (lats[i] > lats[maxIdx]) maxIdx = i;
    }

    float sumLat = 0, sumLon = 0, sumAlt = 0;
    long  sumHdop = 0;
    int   count   = 0;

    for (int i = 0; i < 7; i++) {
        if (i == minIdx || i == maxIdx) continue;
        sumLat  += lats[i];
        sumLon  += lons[i];
        sumAlt  += alts[i];
        sumHdop += hdops[i];
        count++;
    }

    float avgLat  = sumLat  / count;
    float avgLon  = sumLon  / count;
    float avgAlt  = sumAlt  / count;
    float avgHdop = sumHdop / (float)count;

    // Guardar en RTC memory
    lastLat      = (int32_t)(avgLat  * 1e6f);
    lastLon      = (int32_t)(avgLon  * 1e6f);
    lastAlt      = (int16_t)avgAlt;
    lastHdop     = (uint8_t)min((int)avgHdop, 255);
    lastGpsValid = true;
    gpsEsteciclo = true;

    Serial.printf("[GPS] Posicion final — Lat: %.6f  Lon: %.6f  Alt: %dm  HDOP: %.1f\n",
        avgLat, avgLon, lastAlt, avgHdop / 10.0f);

    return true;
}

void gpsRunYApagar() {
    gpsEncender();
    bool ok = gpsBuscarFix();
    gpsApagar();

    if (!ok) {
        Serial.println(lastGpsValid
            ? "[GPS] Sin fix. Usando ultima posicion conocida."
            : "[GPS] Sin fix y sin posicion previa.");
    }
}


// ============================================================================
// SENSOR ULTRASÓNICO — RCWL-1655
// ============================================================================

float medirDistancia() {
    const unsigned long timeout = 60000;

    digitalWrite(TRIG_PIN, LOW);
    delayMicroseconds(4);
    digitalWrite(TRIG_PIN, HIGH);
    delayMicroseconds(20);          // RCWL-1655 requiere mínimo 20µs
    digitalWrite(TRIG_PIN, LOW);

    // Esperar flanco de subida del ECHO
    unsigned long t = micros();
    while (digitalRead(ECHO_PIN) == LOW && micros() - t < timeout);
    if (micros() - t >= timeout) return -1.0;

    // Medir duración del pulso ECHO
    unsigned long echoStart = micros();
    while (digitalRead(ECHO_PIN) == HIGH && micros() - echoStart < timeout);
    if (micros() - echoStart >= timeout) return -1.0;

    unsigned long echoEnd = micros();

    float dist = (echoEnd - echoStart) * 0.0343f / 2.0f;
    return (dist >= 1.0f && dist <= 500.0f) ? dist : -1.0;
}

float medirNivelAgua() {
    digitalWrite(SENSOR_PWR_PIN, HIGH);
    delay(1000);  // RCWL-1655 necesita más tiempo de estabilización que el AJ-SR04M

    float suma    = 0.0;
    int   validas = 0;

    for (int i = 0; i < 3; i++) {
        float d = medirDistancia();
        if (d > 0.0) { suma += d; validas++; }
        delay(100);
    }

    digitalWrite(SENSOR_PWR_PIN, LOW);

    if (validas < 2) {
        Serial.printf("[SENSOR] Error: %d/3 validas\n", validas);
        return -1.0;
    }

    float distPromedio = suma / validas;
    float nivel = (float)ALTURA_SENSOR_CM - distPromedio;

    Serial.printf("[SENSOR] Distancia: %.1f cm  Nivel: %.1f cm  (%d/3 OK)\n",
        distPromedio, nivel, validas);

    return max(nivel, 0.0f);
}


// ============================================================================
// DOWNLINK
// ============================================================================

void procesarDownlink(uint8_t* data, size_t len) {
    if (len < 1) return;

    Serial.printf("[DL] %d bytes | Cmd: 0x%02X\n", len, data[0]);

    switch (data[0]) {

        case 0x01:
            if (len >= 3) {
                uint16_t nuevo = (uint16_t)data[1] | ((uint16_t)data[2] << 8);
                if (nuevo >= 10 && nuevo <= 86400) {
                    sleepInterval = nuevo;
                    Serial.printf("[DL] Intervalo -> %d s\n", sleepInterval);
                } else {
                    Serial.printf("[DL] Intervalo rechazado: %d\n", nuevo);
                }
            }
            break;

        case 0x02:
            Serial.println("[DL] Reiniciando...");
            Serial.flush();
            delay(100);
            esp_restart();
            break;

        case 0x03:
            gpsRequested = true;
            Serial.println("[DL] GPS solicitado para el proximo ciclo.");
            break;

        default:
            Serial.printf("[DL] Cmd desconocido: 0x%02X\n", data[0]);
            break;
    }
}


// ============================================================================
// ENVÍO
// ============================================================================

void do_send(osjob_t* j) {
    if (LMIC.opmode & OP_TXRXPEND) {
        os_setTimedCallback(j, os_getTime() + sec2osticks(5), do_send);
        return;
    }

    float nivel  = medirNivelAgua();
    bool  aguaOk = (nivel >= 0.0);

    uint8_t payload[12] = {0};

    uint8_t flags = 0;
    if (lastGpsValid)  flags |= 0x01;
    if (aguaOk)        flags |= 0x02;
    if (gpsEsteciclo)  flags |= 0x04;
    if (firstBoot)     flags |= 0x08;
    payload[0] = flags;

    uint16_t nivelMm = aguaOk ? (uint16_t)(nivel * 10.0f) : 0xFFFF;
    payload[1] = (nivelMm >> 8) & 0xFF;
    payload[2] =  nivelMm       & 0xFF;

    int32_t lat = lastLat;
    payload[3]  = (lat >> 24) & 0xFF;
    payload[4]  = (lat >> 16) & 0xFF;
    payload[5]  = (lat >>  8) & 0xFF;
    payload[6]  =  lat        & 0xFF;

    int32_t lon = lastLon;
    payload[7]  = (lon >> 24) & 0xFF;
    payload[8]  = (lon >> 16) & 0xFF;
    payload[9]  = (lon >>  8) & 0xFF;
    payload[10] =  lon        & 0xFF;

    payload[11] = lastHdop;

    Serial.printf("[LORA] Enviando %d bytes | Msg #%lu\n", sizeof(payload), messageCount);
    Serial.printf("       flags=0x%02X  nivel=%s cm  lat=%.6f  lon=%.6f\n",
        flags,
        aguaOk ? String(nivel, 1).c_str() : "ERROR",
        lat / 1e6, lon / 1e6);

    LMIC_setTxData2(2, payload, sizeof(payload), 0);
    messageCount++;
}


// ============================================================================
// DEEP SLEEP
// ============================================================================

void entrarDeepSleep() {
    RTC_LMIC      = LMIC;
    session_valid = true;

    Serial.printf("[SLEEP] Durmiendo %d s\n", sleepInterval);
    Serial.flush();

    esp_sleep_enable_timer_wakeup((uint64_t)sleepInterval * 1000000ULL);
    esp_deep_sleep_start();
}


// ============================================================================
// EVENTOS LMIC
// ============================================================================

void onEvent(ev_t ev) {
    switch (ev) {

        case EV_JOINING:
            Serial.println("[LORA] OTAA join...");
            break;

        case EV_JOINED:
            Serial.println("[LORA] Join OK.");
            LMIC_setLinkCheckMode(0);
            do_send(&sendjob);
            break;

        case EV_JOIN_FAILED:
            Serial.println("[LORA] Join fallido.");
            entrarDeepSleep();
            break;

        case EV_REJOIN_FAILED:
            Serial.println("[LORA] Rejoin fallido.");
            entrarDeepSleep();
            break;

        case EV_TXCOMPLETE:
            Serial.println("[LORA] TX completo.");
            Serial.printf("       txrxFlags: 0x%02X  dataLen: %d\n",
                LMIC.txrxFlags, LMIC.dataLen);

            if (LMIC.txrxFlags & TXRX_ACK) {
                Serial.println("[LORA] ACK recibido.");
            }

            if (LMIC.dataLen > 0) {
                Serial.printf("[LORA] Downlink: %d bytes\n", LMIC.dataLen);
                procesarDownlink(LMIC.frame + LMIC.dataBeg, LMIC.dataLen);
            }

            if (firstBoot) {
                Serial.println("[GPS] Primer boot: buscando posicion post-TX...");
                gpsRunYApagar();
            }

            entrarDeepSleep();
            break;

        case EV_TXSTART:
            Serial.println("[LORA] TX iniciado.");
            break;

        case EV_LINK_DEAD:
            Serial.println("[LORA] Link muerto. Forzando re-JOIN.");
            session_valid = false;
            entrarDeepSleep();
            break;

        default:
            break;
    }
}


// ============================================================================
// SETUP
// ============================================================================

void setup() {
    Serial.begin(115200);
    delay(100);

    bootCount++;
    firstBoot    = (esp_sleep_get_wakeup_cause() == ESP_SLEEP_WAKEUP_UNDEFINED);
    gpsEsteciclo = false;

    Serial.printf("\n=== BOOT #%lu | MSG #%lu | Intervalo: %d s | Wakeup: %s ===\n",
        bootCount, messageCount, sleepInterval,
        firstBoot ? "Power ON" : "Timer");

    // --- Pines sensor ---
    pinMode(SENSOR_PWR_PIN, OUTPUT);
    pinMode(TRIG_PIN,        OUTPUT);
    pinMode(ECHO_PIN,        INPUT);
    digitalWrite(SENSOR_PWR_PIN, LOW);
    digitalWrite(TRIG_PIN,       LOW);

    // --- GPS ---
    if (!firstBoot && gpsRequested) {
        gpsRequested = false;
        Serial.println("[GPS] GPS solicitado — corriendo antes del TX...");
        gpsRunYApagar();
    } else {
        pinMode(PNP_GPS,   OUTPUT);
        pinMode(RESET_GPS, OUTPUT);
        digitalWrite(PNP_GPS,   HIGH);
        digitalWrite(RESET_GPS, HIGH);
        if (!firstBoot) {
            Serial.println("[GPS] Usando posicion en RTC.");
        }
    }

    // --- LoRa / LMIC ---
    SPI.begin(LORA_SCK, LORA_MISO, LORA_MOSI, LORA_NSS);
    os_init();

    LMIC_setClockError(MAX_CLOCK_ERROR * 30 / 100);
    LMIC_setAdrMode(1);
    LMIC_setDrTxpow(DR_SF7, 14);
    LMIC_setLinkCheckMode(0);

    if (session_valid) {
        Serial.println("[LORA] Restaurando sesion desde RTC...");
        LMIC = RTC_LMIC;

        ostime_t now = os_getTime();
        LMIC.globalDutyAvail = now;
        LMIC.opmode &= ~(OP_JOINING | OP_REJOIN | OP_TXDATA | OP_POLL);

        Serial.printf("[LORA] FCnt up=%lu dn=%lu\n", LMIC.seqnoUp, LMIC.seqnoDn);
        do_send(&sendjob);
    } else {
        Serial.println("[LORA] Iniciando OTAA...");
        LMIC_reset();
        LMIC_selectSubBand(1);
        LMIC_startJoining();
    }
}


// ============================================================================
// LOOP
// ============================================================================

void loop() {
    os_runloop_once();
}

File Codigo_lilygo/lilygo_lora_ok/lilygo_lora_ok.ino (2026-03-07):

#include <SPI.h>
#include <driver/rtc_io.h>
#include <esp_sleep.h>
#include <hal/hal.h>

// Configuración OTAA
static const u1_t PROGMEM APPEUI[8] = { 
    0x00,0x00,0x00,0x00,0x00,0x00,0x00,0x00
};
void os_getArtEui(u1_t* buf) { memcpy_P(buf, APPEUI, 8); }

static const u1_t PROGMEM DEVEUI[8] = { 
    0xCA,0x22,0x07,0xD0,0x7E,0xD5,0xB3,0x70
};
void os_getDevEui(u1_t* buf) { memcpy_P(buf, DEVEUI, 8); }

static const u1_t PROGMEM APPKEY[16] = { 
    0xD1,0xBA,0xF4,0x60,0x7C,0x4A,0x3F,0x8B,
    0x4F,0xB8,0xCB,0xD3,0xC1,0x65,0xA4,0xAD
};
void os_getDevKey(u1_t* buf) { memcpy_P(buf, APPKEY, 16); }

// Pines LilyGO T3
const lmic_pinmap lmic_pins = {
    .nss = 8,
    .rxtx = LMIC_UNUSED_PIN,
    .rst = 6,
    .dio = {12, 13, 14},
    .rxtx_rx_active = 0,
    .rssi_cal = 10,
    .spi_freq = 8000000
};

// Pines sensor ultrasónico
#define TRIG_PIN        12
#define ECHO_PIN        14
#define SENSOR_PWR_PIN  13

// Intervalo de sleep en segundos (pruebas: 15 s)
const unsigned SLEEP_INTERVAL = 15;

// Contador de reinicios
RTC_DATA_ATTR int bootCount = 0;

// Estructura para sesión LoRaWAN con contador
struct sessionState_t {
    u4_t netid;
    devaddr_t devaddr;
    u1_t nwkKey[16];
    u1_t artKey[16];
    u4_t seqnoUp;        // ← Nuevo: contador de frames
};
RTC_DATA_ATTR sessionState_t savedSession;

static osjob_t sendjob;

// Medir distancia
float medirDistancia() {
    digitalWrite(TRIG_PIN, LOW);
    delayMicroseconds(4);
    digitalWrite(TRIG_PIN, HIGH);
    delayMicroseconds(15);
    digitalWrite(TRIG_PIN, LOW);

    unsigned long timeout = 60000;
    unsigned long start = micros();
    while (digitalRead(ECHO_PIN) == LOW && micros() - start < timeout);
    start = micros();
    while (digitalRead(ECHO_PIN) == HIGH && micros() - start < timeout);
    unsigned long duracion = micros() - start;

    float distancia = duracion * 0.0343 / 2;
    if (distancia <= 1 || distancia > 500) return -1.0;
    return distancia;
}

// Enviar datos
void do_send(osjob_t* j) {
    if (LMIC.opmode & OP_TXRXPEND) {
        Serial.println(F("OP_TXRXPEND - Posponiendo envío"));
        os_setTimedCallback(j, os_getTime() + sec2osticks(5), do_send);
    } else {
        digitalWrite(SENSOR_PWR_PIN, HIGH);
        delay(50);
        float distancia = medirDistancia();
        digitalWrite(SENSOR_PWR_PIN, LOW);

        char payload[20];
        if (distancia < 0) {
            strcpy(payload, "ERROR");
        } else {
            dtostrf(distancia, 4, 1, payload);
        }
        Serial.print("Enviando: ");
        Serial.println(payload);

        LMIC_setTxData2(1, (uint8_t*)payload, strlen(payload), 0);

        // Guardar el seqnoUp justo antes de enviar
        savedSession.seqnoUp = LMIC.seqnoUp;
    }
}

// Entra en deep sleep
void entrarDeepSleep() {
    Serial.print(F("Iniciando deep sleep de "));
    Serial.print(SLEEP_INTERVAL);
    Serial.println(F(" s"));

    // Guardar sesión LoRaWAN completa
    if (LMIC.devaddr != 0) {
        savedSession.netid   = LMIC.netid;
        savedSession.devaddr = LMIC.devaddr;
        memcpy(savedSession.nwkKey, LMIC.nwkKey, 16);
        memcpy(savedSession.artKey, LMIC.artKey, 16);
        // seqnoUp ya se guardó en do_send()
    }

    // Asegurar pines en bajo
    rtc_gpio_set_direction(GPIO_NUM_26, RTC_GPIO_MODE_OUTPUT_ONLY);
    rtc_gpio_set_level(GPIO_NUM_26, 0);
    rtc_gpio_set_direction(GPIO_NUM_32, RTC_GPIO_MODE_OUTPUT_ONLY);
    rtc_gpio_set_level(GPIO_NUM_32, 0);
    rtc_gpio_set_direction(GPIO_NUM_33, RTC_GPIO_MODE_OUTPUT_ONLY);
    rtc_gpio_set_level(GPIO_NUM_33, 0);
    digitalWrite(lmic_pins.rst, LOW);

    // Mantener activo solo el periférico RTC
    esp_sleep_pd_config(ESP_PD_DOMAIN_RTC_PERIPH, ESP_PD_OPTION_ON);
    uint64_t wakeUs = (uint64_t)SLEEP_INTERVAL * 1000000ULL;
    esp_sleep_enable_timer_wakeup(wakeUs);

    esp_deep_sleep_start();
}

void onEvent(ev_t ev) {
    Serial.print(os_getTime());
    Serial.print(F(": "));
    switch (ev) {
        case EV_JOINED:
            Serial.println(F("EV_JOINED"));
            LMIC_setLinkCheckMode(0);
            do_send(&sendjob);
            break;
        case EV_TXCOMPLETE:
            Serial.println(F("EV_TXCOMPLETE"));
            entrarDeepSleep();
            break;
        case EV_JOIN_FAILED:
        case EV_REJOIN_FAILED:
            Serial.println(F("JOIN_FAILED/Rejoin"));
            entrarDeepSleep();
            break;
        default:
            Serial.print(F("Evento: "));
            Serial.println(ev, HEX);
    }
}

void setup() {
    Serial.begin(115200);
    delay(3000);

    bootCount++;
    Serial.println(F("\n=== MONITOREO HIDRICO ==="));
    Serial.print(F("Reinicio #")); Serial.println(bootCount);

    // Causa de wakeup
    esp_sleep_wakeup_cause_t reason = esp_sleep_get_wakeup_cause();
    Serial.print(F("Wakeup cause: ")); Serial.println(reason);

    // Pines
    pinMode(SENSOR_PWR_PIN, OUTPUT);
    digitalWrite(SENSOR_PWR_PIN, LOW);
    pinMode(TRIG_PIN, OUTPUT);
    pinMode(ECHO_PIN, INPUT);
    digitalWrite(TRIG_PIN, LOW);

    // Prueba sensor
    digitalWrite(SENSOR_PWR_PIN, HIGH);
    delay(50);
    float test = medirDistancia();
    digitalWrite(SENSOR_PWR_PIN, LOW);
    Serial.print(F("Test sensor: ")); Serial.println(test);

    // Init LoRa
    SPI.begin(5, 19, 27, 18);
    pinMode(lmic_pins.rst, OUTPUT);
    digitalWrite(lmic_pins.rst, LOW);
    delay(100);
    digitalWrite(lmic_pins.rst, HIGH);
    delay(1000);

    os_init();
    LMIC_reset();

    // Restaurar sesión o unir
    if (savedSession.devaddr != 0) {
        LMIC_setSession(
            savedSession.netid,
            savedSession.devaddr,
            savedSession.nwkKey,
            savedSession.artKey
        );
        LMIC.seqnoUp = savedSession.seqnoUp;  // <-- Restaurar contador
        Serial.print(F("Sesión restaurada, seqnoUp = "));
        Serial.println(LMIC.seqnoUp);
        LMIC_setLinkCheckMode(0);
        LMIC_setDrTxpow(DR_SF7, 14);
        LMIC_selectSubBand(1);
        do_send(&sendjob);
    } else {
        Serial.println(F("Iniciando unión OTAA..."));
        LMIC_setLinkCheckMode(0);
        LMIC_setDrTxpow(DR_SF7, 14);
        LMIC_selectSubBand(1);
        LMIC_startJoining();
    }
}

void loop() {
    os_runloop_once();
}

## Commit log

2025-08-19 Inicial: proyecto KiCad
    [PcbArroz.kicad_pcb, PcbArroz.kicad_sch]
2025-08-20 Mejoras de lo ya ruteado / falta uc
    [PcbArroz.kicad_pcb]
2025-08-21 falta uc
    [PcbArroz.kicad_pcb]
2025-09-22 Revision general pcb
    [PcbArroz.kicad_pcb, PcbArroz.kicad_sch]
2025-10-05 mounting holes
    [PcbArroz.kicad_pcb]
2025-10-18 V1 a revisar
    [PcbArroz.kicad_pcb]
2025-10-21 agregadas capas de power y gnd
    [PcbArroz.kicad_pcb]
2025-10-25 Pcb v1
    [PcbArroz.kicad_pcb, PcbArroz.kicad_sch]
2025-10-28 V1 final
    [PcbArroz.kicad_pcb]
2025-10-28 Pcb v1.0
    [PcbArroz.kicad_pcb]
2025-10-28 V1 + via rules .3mm
    [PcbArroz.kicad_pcb]
2025-10-28 V2 +Q1 (Falta DRS)
    [Lista de materiales LoRa+GPS.xlsx, PCB_LoRa+GPS.kicad_pcb, PCB_LoRa+GPS.kicad_sch]
2025-10-28 V2 DRC - Revisar
    [PCB_LoRa+GPS.kicad_pcb]
2025-10-28 agregados pads
    [PcbArroz.kicad_pcb, PcbArroz.kicad_sch]
2025-10-28 Pads, v1 de chris (sin LoRa+GPS)
    [PcbArroz.kicad_pcb]
2025-10-28 pads, gerbers, logo ucu, iniciales y fecha
    [PcbArroz.kicad_pcb]
2025-10-29 V2 DRC checked
    [Lista de materiales LoRa+GPS.xlsx, PCB_LoRa+GPS.kicad_pcb, PCB_LoRa+GPS.kicad_sch]
2025-10-29 Varicela y footpads
    [PCB_LoRa+GPS.kicad_pcb, PCB_LoRa+GPS.kicad_sch]
2025-10-29 correcciones drc
    [PCB_LoRa+GPS.kicad_pcb, PcbArroz.kicad_pcb]
2025-10-29 V2 Gerbers
    [PCB_LoRa+GPS.kicad_pcb, PcbArroz.kicad_pcb]
2025-10-30 V2 Gerbers corregidos
    [PCB_LoRa+GPS.kicad_pcb]
2025-12-18 falta rutear esp v3
    [V3.kicad_pcb, V3.kicad_sch]
2025-12-18 Version 3 completa tal como en PC
    [V3.kicad_pcb, V3.kicad_sch]
2025-12-18 v3 para revisar
    [V3.kicad_sch]
2025-12-20 V3 para revisarr
2025-12-20 V3 para revisarrrrr
    [V3.kicad_pcb]
2025-12-21 V3 final
    [V3.kicad_pcb, V3.kicad_sch]
2026-03-07 Firmware Final
    [V3.kicad_pcb]
